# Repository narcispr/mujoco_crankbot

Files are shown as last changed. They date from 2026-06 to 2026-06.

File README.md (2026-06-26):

# Crank Bot

Crank Bot is a basic four-legged robot project. The name comes from its black look, but mechanically it is a small quadruped that can be 3D printed and assembled.

The repository includes the STL files in [`assets/`](assets/) and a first basic MuJoCo simulation model.

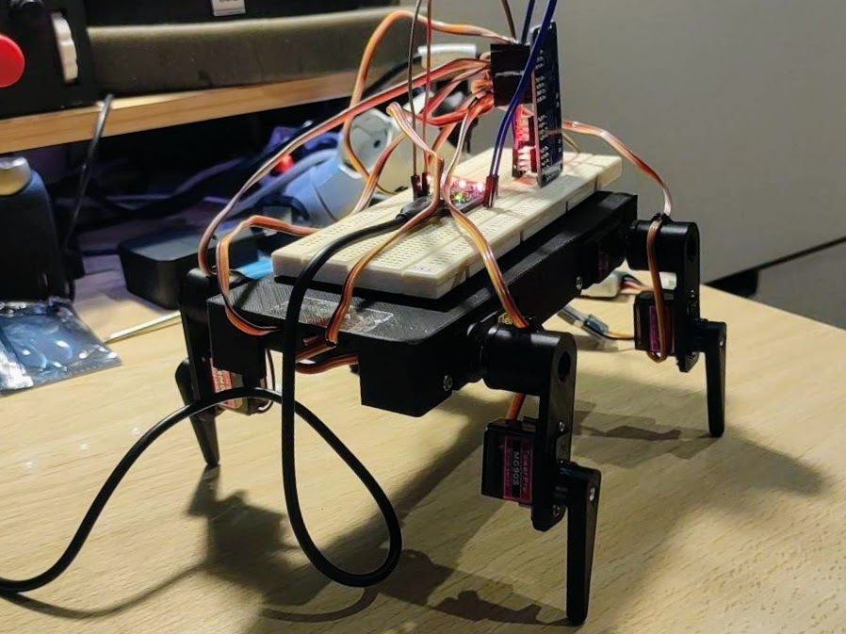
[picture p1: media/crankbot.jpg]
Crank Bot


## Bill of Materials

Initial BOM:

- 4x MG995 or MG996 servos
- 4x MG90S servos
- 1x PCA9685 servo driver
- 1x ESP32-C3 microcontroller
- 1x 5 V or 6 V BEC, minimum 5 A, preferably 10 A
- 1x MP1584 buck converter for the microcontroller
- 1x 2S LiPo battery
- 3D printed parts from [`assets/`](assets/)

## Simulation

The repository currently contains a basic MuJoCo XML model of the robot. A Python script will be added later to interact with the simulation.

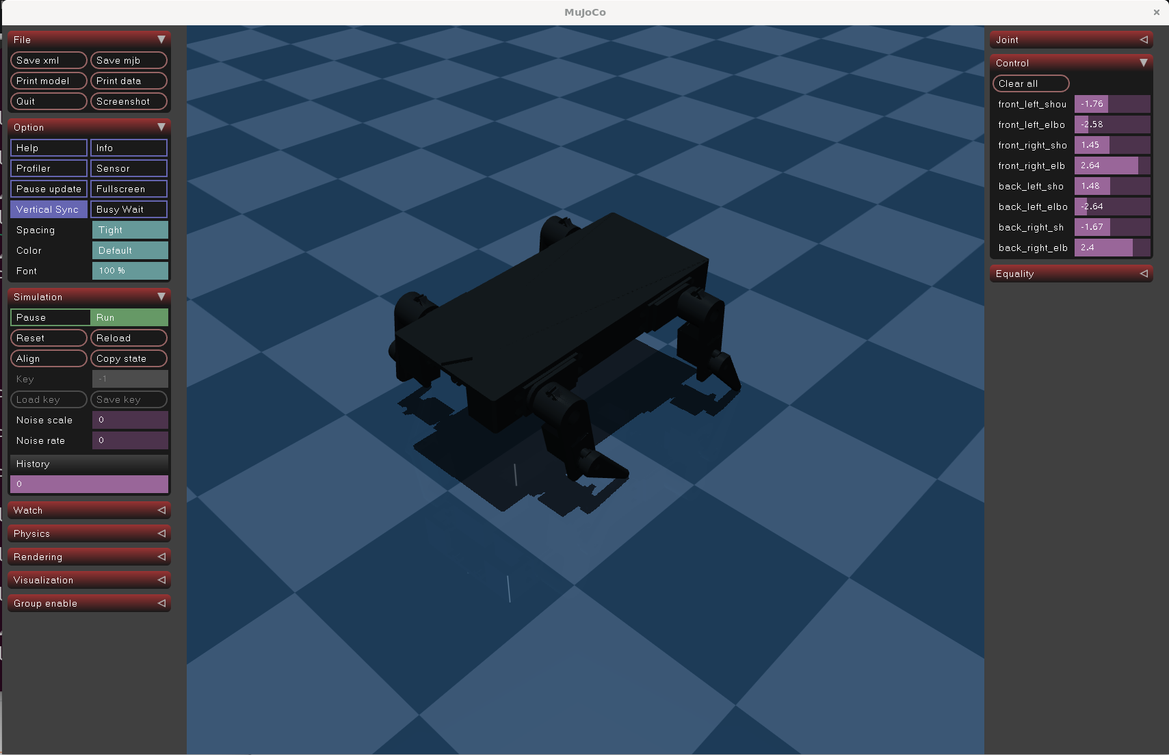
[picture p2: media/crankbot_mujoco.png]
Crank Bot in MuJoCo


## Control del robot real amb ESP32-C3

Aquesta versió substitueix el control Arduino bàsic de [`firmware/robo_dog_sketch.ino`](firmware/robo_dog_sketch.ino) per un bridge WiFi amb ESP32-C3:

- Firmware ESP32-C3: [`firmware/esp32_c3_servo_bridge/esp32_c3_servo_bridge.ino`](firmware/esp32_c3_servo_bridge/esp32_c3_servo_bridge.ino)
- Client PC: [`scripts/robot_client.py`](scripts/robot_client.py)
- Presets visibles: [`scripts/config/robot_presets.json`](scripts/config/robot_presets.json)

El PC envia 8 setpoints normalitzats en l'interval `[-1, 1]` per UDP. L'ESP els converteix a polsos PWM per al PCA9685 i limita la velocitat de canvi amb els paràmetres `minRpm` i `maxRpm` definits per cada servo. Això és un limitador de consigna: els MG995/MG996/MG90S no donen feedback de posició, per tant l'ESP no pot mesurar la RPM real.

Ordre dels 8 motors:

| Índex | Motor | Canal PCA9685 inicial |
| ---: | --- | ---: |
| 0 | `front_left_shoulder` | 8 |
| 1 | `front_left_elbow` | 9 |
| 2 | `front_right_shoulder` | 12 |
| 3 | `front_right_elbow` | 13 |
| 4 | `back_left_shoulder` | 10 |
| 5 | `back_left_elbow` | 11 |
| 6 | `back_right_shoulder` | 14 |
| 7 | `back_right_elbow` | 15 |

### Connexions

Connexions recomanades:

- PCA9685 `V+` a la font/BEC de servos de 5-6 V.
- PCA9685 `GND`, ESP32-C3 `GND` i GND de la font de servos units.
- PCA9685 `VCC` a `3V3` de l'ESP32-C3.
- PCA9685 `SDA` al GPIO `8` de l'ESP32-C3.
- PCA9685 `SCL` al GPIO `9` de l'ESP32-C3.
- Servos als canals `8..15` del PCA9685 segons la taula anterior.

No alimentis els servos des de l'USB ni des del pin `5V` de l'ESP. Els servos han de tenir una alimentació separada amb prou corrent, i només han de compartir GND amb l'ESP.

Si la teva placa ESP32-C3 no exposa I2C als GPIO `8/9`, canvia aquests valors al firmware:

```cpp
const int I2C_SDA_PIN = 8;
const int I2C_SCL_PIN = 9;
```

### Instal·lació de l'Arduino IDE

1. Instal·la Arduino IDE 2.x.
2. A `File > Preferences`, afegeix aquest URL a `Additional boards manager URLs`:

   ```text
   https://espressif.github.io/arduino-esp32/package_esp32_index.json
   ```

3. A `Tools > Board > Boards Manager`, instal·la `esp32` by Espressif Systems.
4. A `Library Manager`, instal·la:
   - `Adafruit PWM Servo Driver Library`
   - `Adafruit BusIO`
5. Obre [`firmware/esp32_c3_servo_bridge/esp32_c3_servo_bridge.ino`](firmware/esp32_c3_servo_bridge/esp32_c3_servo_bridge.ino).
6. A `Tools > Board`, tria la teva placa ESP32-C3. Si no surt exactament, prova `ESP32C3 Dev Module`.
7. Connecta l'ESP per USB i tria el port a `Tools > Port`.
8. Prem `Upload`.

Si la placa no entra en mode programació, mantén premut `BOOT`, prem i deixa anar `RESET`, i torna a pujar el firmware.

### Configuració WiFi de l'ESP

Per defecte, l'ESP crea una xarxa pròpia:

- SSID: `crankbot-esp32`
- Password: `crankbot123`
- IP de l'ESP: `192.168.4.1`
- Port UDP: `4210`

Connecta el PC a aquesta WiFi abans d'executar el client Python.

Si prefereixes que l'ESP entri a la teva WiFi, omple aquests camps al firmware:

```cpp
const char *WIFI_SSID = "nom_de_la_wifi";
const char *WIFI_PASSWORD = "password";
```

En aquest mode, obre el Serial Monitor a `115200` baud per veure la IP assignada i passa-la al client amb `--host`.

### Calibratge dels servos

Al firmware, cada servo té:

```cpp
{"front_left_shoulder", 8, 500, 1500, 2750, 2.0, 50.0, false}
```

Els camps són:

| Camp | Significat |
| --- | --- |
| Nom | Nom del joint |
| Canal | Canal del PCA9685 |
| `minUs` | Pols per a setpoint `-1` |
| `centerUs` | Pols per a setpoint `0` |
| `maxUs` | Pols per a setpoint `1` |
| `minRpm` | Pas mínim quan hi ha moviment |
| `maxRpm` | Velocitat màxima de canvi de consigna |
| `invert` | Inverteix el signe del setpoint |

Els valors inicials surten del sketch Arduino antic: `500 us`, `2500 us`, `2750 us` i centre `1500 us`. Abans d'executar la policy, prova motor a motor amb valors petits, per exemple `-0.2`, `0.0`, `0.2`, i ajusta `minUs`, `centerUs`, `maxUs` i `invert`.

### Client Python

Des del PC principal, crea l'entorn Python i instal·la dependències:

```bash
python -m venv .venv
source .venv/bin/activate
pip install -r requirements.txt
```

Per veure els presets disponibles:

```bash
python scripts/robot_client.py list-presets
```

Per enviar una posició predefinida:

```bash
python scripts/robot_client.py preset center
python scripts/robot_client.py preset stand_approx --duration 3
python scripts/robot_client.py preset folded_approx --duration 3
```

Per defecte, aquests comandaments també obren MuJoCo i mostren el mateix moviment al simulador. Si només vols enviar a l'ESP sense simulador:

```bash
python scripts/robot_client.py --disable-mujoco preset stand_approx --duration 3
```

Per enviar 8 valors manuals:

```bash
python scripts/robot_client.py manual 0 0 0 0 0 0 0 0
python scripts/robot_client.py manual 0.2 0 -0.2 0 0.2 0 -0.2 0 --duration 2
```

En mode manual amb MuJoCo actiu, els 8 valors manuals són el target del simulador. El client llegeix contínuament les posicions reals dels joints simulats (`qpos`) i envia aquestes posicions a l'ESP. Per saltar aquest comportament i enviar directament els 8 valors manuals:

```bash
python scripts/robot_client.py --disable-mujoco manual 0.2 0 -0.2 0 0.2 0 -0.2 0 --duration 2
```

Per comprovar comunicació amb l'ESP:

```bash
python scripts/robot_client.py command PING
python scripts/robot_client.py command STATUS
python scripts/robot_client.py command STOP
```

Si l'ESP està connectat a una WiFi externa, usa la IP que surt pel Serial Monitor:

```bash
python scripts/robot_client.py --host 192.168.1.123 command STATUS
```

### Executar una policy al robot

El client pot carregar una policy SAC de Stable-Baselines3 i enviar les accions al robot:

```bash
python scripts/robot_client.py policy --model logs/crankbot_walk_gym/run_xxx/final_model.zip
```

Si no passes `--model`, busca l'últim model sota `logs/crankbot_walk_gym`.

El programa demana:

- `Goal range in meters`: distància inicial al goal.
- `Goal bearing in degrees`: angle relatiu del goal respecte al robot.
- `Maximum execution time in seconds`: temps màxim d'execució.

També pots passar-ho sense prompts:

```bash
python scripts/robot_client.py policy \
  --model logs/crankbot_walk_gym/run_xxx/final_model.zip \
  --goal-range 0.5 \
  --goal-bearing-deg 0 \
  --max-time 8
```

Abans d'executar la policy, el client envia `q_stand` durant `--prime-duration`, perquè les policies s'han entrenat sortint d'una postura propera a `q_stand`.

Amb MuJoCo actiu, que és el comportament per defecte, el range i bearing inicials creen un goal visible al `goal_site` del simulador. A partir d'aquí, cada crida a la policy usa el range i bearing actuals entre el robot simulat i aquest goal. El feedback del goal ve del simulador, no del robot real.

Si vols executar la policy sense obrir ni avançar MuJoCo:

```bash
python scripts/robot_client.py --disable-mujoco policy \
  --model logs/crankbot_walk_gym/run_xxx/final_model.zip \
  --goal-range 0.5 \
  --goal-bearing-deg 0 \
  --max-time 8
```

Per al robot real, entrena o carrega una policy amb observacions d'actor, és a dir amb `--disable-privileged`. Una policy entrenada amb l'observació privilegiada de 80 valors espera estat de simulador que el robot real no té.

Important: el control dels servos reals continua sent open-loop. El client sap les consignes que ha enviat, l'historial d'accions, la fase de la marxa i, si MuJoCo està actiu, el goal respecte al robot simulat. No sap si el robot real ha avançat o ha girat. Si afegeixes odometria, càmera o localització externa, s'ha d'actualitzar `goal_range` i `goal_bearing` dins de [`scripts/robot_client.py`](scripts/robot_client.py).

## Training

The Gymnasium environment is [`scripts/crankbot_walk_gym_env.py`](scripts/crankbot_walk_gym_env.py). It wraps the CPU MuJoCo vectorized environment as a single-env Gym API for SAC training.

| Mode | Observation size | Contents |
| --- | ---: | --- |
| Default | 80 | Actor observation + privileged simulator state |
| `--disable-privileged` | 68 | Actor observation only |

Actor observation:

| Term | Size | Meaning |
| --- | ---: | --- |
| `q_cmd_history` | 32 | 4-step history of 8 commanded joint targets, as `q_cmd - q_stand` |
| `action_history` | 32 | 4-step history of 8 normalized actions |
| `goal_bearing / pi` | 1 | Relative goal direction |
| `goal_range / target_goal_range` | 1 | Normalized distance to the goal |
| `sin(phase), cos(phase)` | 2 | Gait phase signal |

Standing reference pose:

| Joint order | `front_left_shoulder` | `front_left_elbow` | `front_right_shoulder` | `front_right_elbow` | `back_left_shoulder` | `back_left_elbow` | `back_right_shoulder` | `back_right_elbow` |
| --- | ---: | ---: | ---: | ---: | ---: | ---: | ---: | ---: |
| `q_stand` rad | -1.15 | -2.34 | 1.15 | 2.34 | 2.00 | -2.34 | -2.00 | 2.34 |

Privileged extra observation:

| Term | Size | Meaning |
| --- | ---: | --- |
| `base_velocity_body` | 3 | Local base velocity, including yaw rate |
| `base_z` | 1 | Base height |
| `roll_pitch` | 2 | Base tilt |
| `foot_contacts` | 4 | Foot contact flags |
| `leg_contact` | 1 | Upper-leg ground contact |
| `body_contact` | 1 | Base ground contact |

Actions are 8 normalized joint command increments:

$$
q_{cmd,t+1} = clip(q_{cmd,t} + a_t \cdot action\_scale,\ q_{min},\ q_{max}),\quad a_t \in [-1, 1]^8
$$

Reward:

$$
r = -tanh(goal\_range / goal\_reward\_scale) - c_s ||a_t-a_{t-1}||^2 - c_a ||a_t||^2 - p_{idle} - p_{leg} - p_{lower} - p_{body} - p_{fall}
$$

| Term | Meaning |
| --- | --- |
| $-tanh(goal\_range / goal\_reward\_scale)$ | Goal progress term; less negative as the robot gets closer to the target |
| $-c_s \|\|a_t-a_{t-1}\|\|^2$ | Smoothness penalty for abrupt action changes |
| $-c_a \|\|a_t\|\|^2$ | Action magnitude penalty |
| $-p_{idle}$ | Penalty for sending nearly zero action while the goal is not reached |
| $-p_{leg}$ | Penalty when upper-leg collision geoms touch the floor |
| $-p_{lower}$ | Penalty when lower-leg collision geoms touch the floor |
| $-p_{body}$ | Penalty when the base touches the floor |
| $-p_{fall}$ | Fall penalty when base height is below the fall threshold |

### Training MJX/Warp amb Playground

Per entrenar a GPU amb l'entorn MJX actor-only i provar el backend Warp/Playground, crea un venv nou amb Python 3.11 o superior. Un `uv pip install` sobre el `.venv` antic no canvia la versió de Python.

```bash
uv venv --python 3.11
source .venv/bin/activate
uv pip install -r requirements.txt
```

Entrenament PPO amb 2048 entorns:

```bash
python scripts/train.mjx.py \
  --algorithm ppo \
  --backend warp \
  --num-envs 2048 \
  --num-eval-envs 256 \
  --timesteps 10000000
```

Entrenament SAC:

```bash
python scripts/train.mjx.py \
  --algorithm sac \
  --backend warp \
  --num-envs 2048 \
  --num-eval-envs 256 \
  --timesteps 10000000
```

Notes ràpides:

- Si surt `backend='warp'` no disponible, comprova que el venv sigui Python 3.11+ i que `warp-lang` i `playground[learning]` s'hagin instal·lat.
- Si veus errors de CUDA/JAX, revisa que la versió instal·lada de `jax[cuda13]` encaixi amb el driver de la GPU.
- Si vols comprovar el pipeline abans d'un run llarg, baixa `--num-envs 32 --num-eval-envs 8 --timesteps 1000 --logger none --no-checkpoints`.
- Si Warp continua donant problemes, prova temporalment `--backend mjx` per separar errors de l'entorn dels errors del backend.

After training with SAC, this behavior has been obtained:

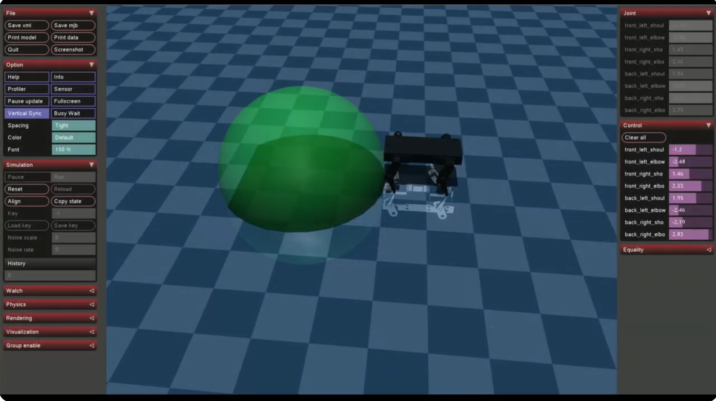
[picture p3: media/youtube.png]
Watch the video (https://youtu.be/LTj4IBt9pyA)


## Future Work

- Include some dynamics/noise randomization in the learning.
- Execute the trained policy in the real hardware.

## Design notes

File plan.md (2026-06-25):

# mplementation plan for rsl_rl + PPO + privileged_obs

## 1. Goal

Implement a MuJoCo CPU vectorized environment for the 8-servo quadruped robot using:

- rsl_rl
- PPO
- asymmetric actor-critic
- actor observations based only on information available on the real robot
- privileged critic observations using simulator-only state

The robot already exists as a MuJoCo XML model at file crank_bot.xml with:

- free root body
- 8 position-controlled joints
- visualization meshed geoms
- 2 x contact geoms per leg + 1 for the body

The environment will train a policy to track commanded forward velocity and yaw velocity.

## 2. Simulation timing

Use MuJoCo at:

simulation_dt = 0.002 s
simulation_frequency = 500 Hz

Use policy/control at:

dt_control = 0.1 s
control_frequency = 10 Hz
decimation = 50

That means:

1 policy step = 50 MuJoCo mj_step calls

Episode length:

max_episode_steps = 80
episode_time = 8.0 s

Success is defined if during the last 20 steps the average speed matches (with some error) the desired speed.

Do not terminate on success. Use success only as a curriculum signal.

## 3. Action definition

The action is continuous:

action ∈ [-1, 1]^8

Each action component represents an increment in commanded joint target.

Use different scales for shoulders and elbows:

shoulder_action_scale = 0.07 rad/step
elbow_action_scale    = 0.10 rad/step

Assume a fixed joint ordering, for example:

0 front_left_shoulder
1 front_left_elbow
2 front_right_shoulder
3 front_right_elbow
4 back_left_shoulder
5 back_left_elbow
6 back_right_shoulder
7 back_right_elbow

Define:

action_scale = [
    0.07, 0.10,
    0.07, 0.10,
    0.07, 0.10,
    0.07, 0.10,
]

Update commanded positions:

q_cmd_next = q_cmd_current + action_scale * action

Articulation limits and standing pose (q_stand) are defined as:

- front_left_shoulder => limits: [-pi, 0], standing -1.15
- front_left_elbow => limits: [-pi, 0], standing -2.34
- front_right_shoulder => limits: [0, pi], standing 1.15
- front_right_elbow => limits: [0, pi], standing 2.34
- back_left_shoulder => limits: [0, pi], standing 2
- back_left_elbow => limits: [-pi, 0], standing -2.34
- back_right_shoulder => limits: [-pi, 0], standing -2
- back_right_elbow => limits: [0, pi], standing 2.34

Clip around the standing pose:

q_cmd_next = clip(q_cmd_next, q_stand - q_limit, q_stand + q_limit)

Start with conservative limits:

The MuJoCo position actuators receive:

data.ctrl[:] = q_cmd_next

assuming each actuator ctrlrange is in radians and matches the joint target range.

## 4. Desired commands

At each episode reset, sample one command and keep it constant for the full episode.

Actor receives normalized commands:

- command_vx = vx_des / GLOBAL_MAX_VX
- command_wz = wz_des / GLOBAL_MAX_WZ

where

- vx_des = uniform(-current_max_vx, current_max_vx)
- wz_des = uniform(-current_max_wz, current_max_wz)

Start with small velocities:

current_max_vx = 0.05 m/s
current_max_wz = 0.20 rad/s

Later curriculum may increase them to:

current_max_vx = 0.10 m/s
current_max_wz = 0.35 rad/s

Then:

current_max_vx = 0.15 m/s
current_max_wz = 0.50 rad/s

Define 

GLOBAL_MAX_VX  = 0.15 m/s
GLOBAL_MAX_WZ = 0.50 rad/s

## 5. Gait phase

Maintain a phase variable per environment:

phase += 2.0 * pi * gait_frequency * dt_control
phase = phase % (2.0 * pi)

Initial value at reset:

phase = uniform(0, 2*pi)

Start with:

gait_frequency = 1.0 Hz

Observation uses:

sin_phase = sin(phase)
cos_phase = cos(phase)

## 6. Actor observation

The actor should not receive MuJoCo qpos or qvel directly, because the real MG996/MG90 servos do not provide real feedback.

Use commanded joint history instead:

q_cmd_history, not q_real

Use relative commanded positions:

q_cmd_rel = q_cmd - q_stand

Use history length:

N = 4

Actor observation:

actor_obs =
[
  q_cmd_rel[t],
  q_cmd_rel[t-1],
  q_cmd_rel[t-2],
  q_cmd_rel[t-3],

  action[t-1],
  action[t-2],
  action[t-3],
  action[t-4],

  command_vx, 
  command_wz,

  sin(phase),
  cos(phase)
]

Dimension:

4 * 8 + 4 * 8 + 2 + 2 = 68

Rationale:

q_cmd_history:
  approximates what the real robot knows: what positions were commanded.

action_history:
  gives the policy recent control intent, especially useful when clipping,
  saturation, delays, and different shoulder/elbow scales are present.

command_vx_norm and command_wz_norm:
  tell the policy what the user wants.

phase:
  provides an internal periodic clock that helps discover rhythmic gaits.

## 7. Critic observation

Use privileged information for the critic.

Critic observation:

critic_obs =
[
  actor_obs,

  measured_vx_body,
  measured_vy_body,
  measured_wz_body,

  base_z,
  roll,
  pitch,

  foot_contact_FL,
  foot_contact_FR,
  foot_contact_BL,
  foot_contact_BR,

  body_contact
]

Dimension:

68 + 3 + 3 + 4 + 1 = 79

Where:

measured_vx_body:
  robot forward velocity expressed in body frame

measured_vy_body:
  lateral velocity in body frame

measured_wz_body:
  yaw rate in body frame or world z yaw rate

base_z:
  root/base height

roll, pitch:
  body orientation, excluding yaw

foot contacts:
  booleans or floats from MuJoCo contact detection

body_contact:
  1 if torso/base touches the floor, else 0

Use the body named "base" for the spoeed height and orientation and the spheres named "[front/back]_[left/right]_lower_leg_foot" for the feet contacts.

Rationale:

The critic is allowed to see simulator-only information.
This improves value estimation during PPO training.
The actor will not receive these quantities at deployment time.

## 8. Reward

Use:

evx = (vx_des - vx_measured) / GLOBAL_MAX_VX
ewz = (wz_des - wz_measured) / GLOBAL_MAX_WZ

r_vx = exp(-k_vx * evx**2)
r_wz = exp(-k_wz * ewz**2)

reward = (
    1.0 * r_vx
    + 0.5 * r_wz
    - 0.005 * np.sum((action - last_action)**2)
    - 0.001 * np.sum(action**2)
    - 1.0 * body_contact
    - 2.0 * fall
)

Initial constants:

k_vx = 4.0
k_wz = 2.0

## 9. Body contact penalty

Body contact:

body_contact = base collision geom touches floor

use body_contact as a penalty but not termination.

## 10. Success metric for curriculum

Do not terminate on success initially.

Define success at episode end:

success = (
  not body_contact
  and mean_abs_vx_error_last_20_steps < vx_threshold
  and mean_abs_wz_error_last_20_steps < wz_threshold
)

Initial thresholds:

vx_threshold = 0.025 m/s
wz_threshold = 0.05 rad/s

Later tighten:

vx_threshold = 0.02 m/s
wz_threshold = 0.04 rad/s

Then:

vx_threshold = 0.015 m/s
wz_threshold = 0.035 rad/s

Track:

success_rate = successes_last_100_episodes / 100. Ensure that 100 episodes have already completed.

Use success metric to update all curriculum variables (see 11)

## 11. Adaptive curriculum

Maintain curriculum variables:

current_max_vx
current_max_wz
initial_pose_noise
regularization_scale
success_thresholds

Initial values:

current_max_vx = 0.05
current_max_wz = 0.00
initial_pose_noise = 0.10 rad
smoothness_coef = 0.002
action_coef = 0.0005
body_contact_penalty = 0.5

Target final values:

max_vx = 0.15
max_wz = 0.50
initial_pose_noise = 0.50 rad
smoothness_coef = 0.005
action_coef = 0.001
body_contact_penalty = 1.0

Every time:

success_rate_last_100 > 0.75

increase difficulty slightly:

max_vx *= 1.15
max_wz += 0.05
initial_pose_noise += 0.03
smoothness_coef += small_increment
tighten success thresholds slightly

Clamp to maximum values.

I would not start with backward walking. Start forward only.

## 12. Reset logic

At reset:

q_cmd = q_stand + uniform(-initial_pose_noise, +initial_pose_noise)
q_cmd = clip(q_cmd, q_stand - q_limit, q_stand + q_limit)

Set MuJoCo joint positions close to q_cmd, but optionally add small physical mismatch:

q_real = q_cmd + uniform(-servo_position_error, servo_position_error)

Start with:

servo_position_error = 0.0

Later:

servo_position_error = 0.03 rad

Set velocities to small random values:

qvel = uniform(-0.05, 0.05)

Set root pose:

base at nominal height
small roll/pitch noise
yaw random optional

Initialize histories:

q_cmd_history[:] = q_cmd - q_stand
action_history[:] = 0
phase = uniform(0, 2*pi)

## 13. Environment API for rsl_rl

Implement a vectorized environment class with buffers:

self.obs_buf              # actor obs, shape [num_envs, 68]
self.privileged_obs_buf   # critic obs, shape [num_envs, 79]
self.rew_buf              # shape [num_envs]
self.reset_buf            # shape [num_envs]
self.episode_length_buf   # shape [num_envs]

Required methods conceptually:

reset()
step(actions)
get_observations()
get_privileged_observations()

Depending on exact rsl_rl version, match the expected VecEnv interface.

The step(actions) function:

1. clip actions to [-1, 1]
2. update q_cmd with shoulder/elbow scales
3. clip q_cmd around q_stand
4. write q_cmd to MuJoCo actuator controls
5. run decimation MuJoCo steps
6. compute contacts
7. compute base velocities/orientation
8. compute reward
9. compute done/reset
10. update histories
11. fill obs_buf and privileged_obs_buf
12. reset environments that are done
15. Training configuration

Start with:

num_envs = 32
control_frequency = 10 Hz
episode_steps = 80

PPO rough starting values:

num_steps_per_env = 80
num_learning_epochs = 5
num_mini_batches = 4
gamma = 0.99
lam = 0.95
learning_rate = 3e-4
entropy_coef = 0.01
clip_param = 0.2
desired_kl = 0.01

Actor-critic network:

actor hidden dims:  [256, 256, 128]
critic hidden dims: [256, 256, 128]
activation: ELU or Tanh

Observation normalization is strongly recommended.

## Notes

Be sure that the training autoreset resets not only physics state and obs, but also arbitrary custom state. Since this environment’s observation is mostly command/history state, add something to resets/resample those fields instead of silently carrying stale histories across episodes.

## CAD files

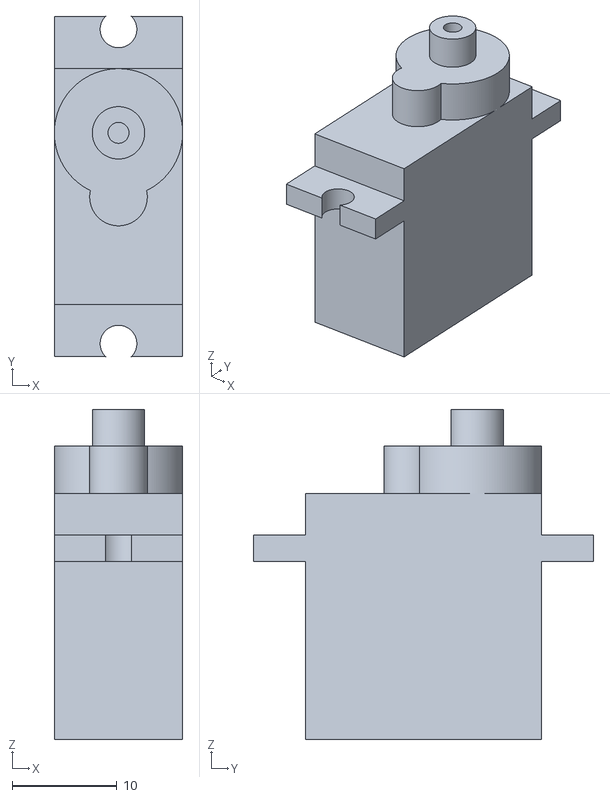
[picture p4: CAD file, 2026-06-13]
assets/mg90.stl
12.2 x 32.5 x 31.5

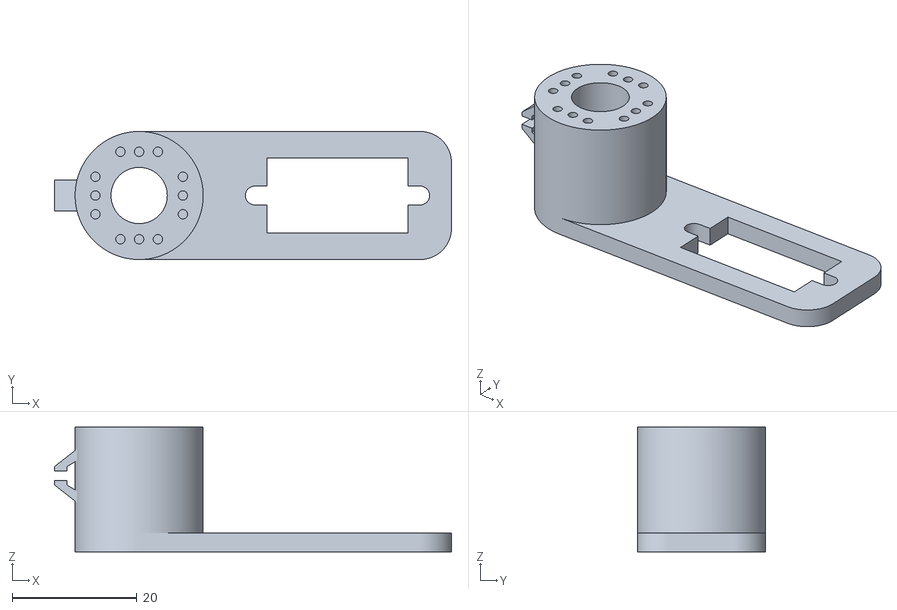
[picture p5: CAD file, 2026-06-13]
assets/leg1.stl
63.6 x 20.5 x 20.0

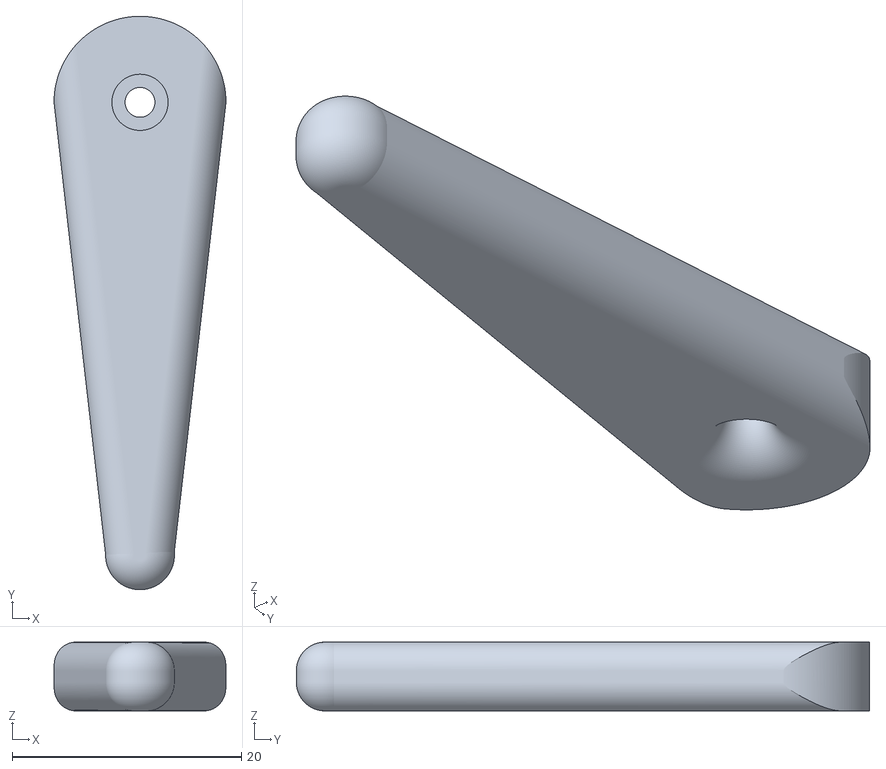
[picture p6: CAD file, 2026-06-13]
assets/leg2.stl
15.0 x 50.0 x 6.00

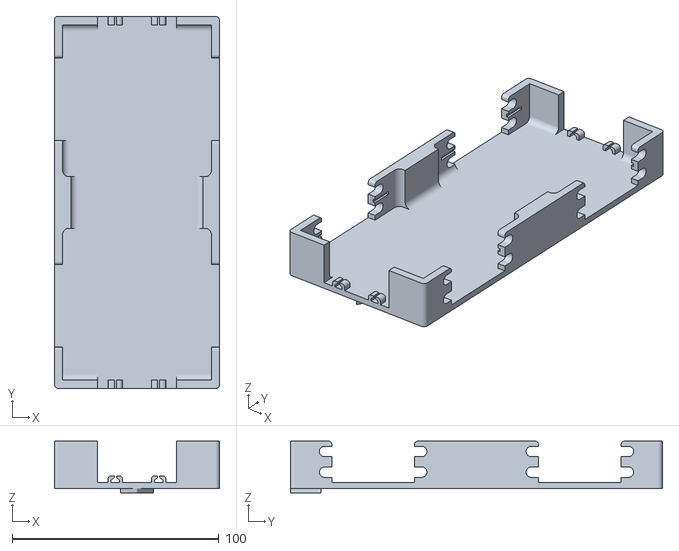
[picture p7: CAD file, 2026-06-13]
assets/base2b.stl
80.0 x 180.0 x 25.0

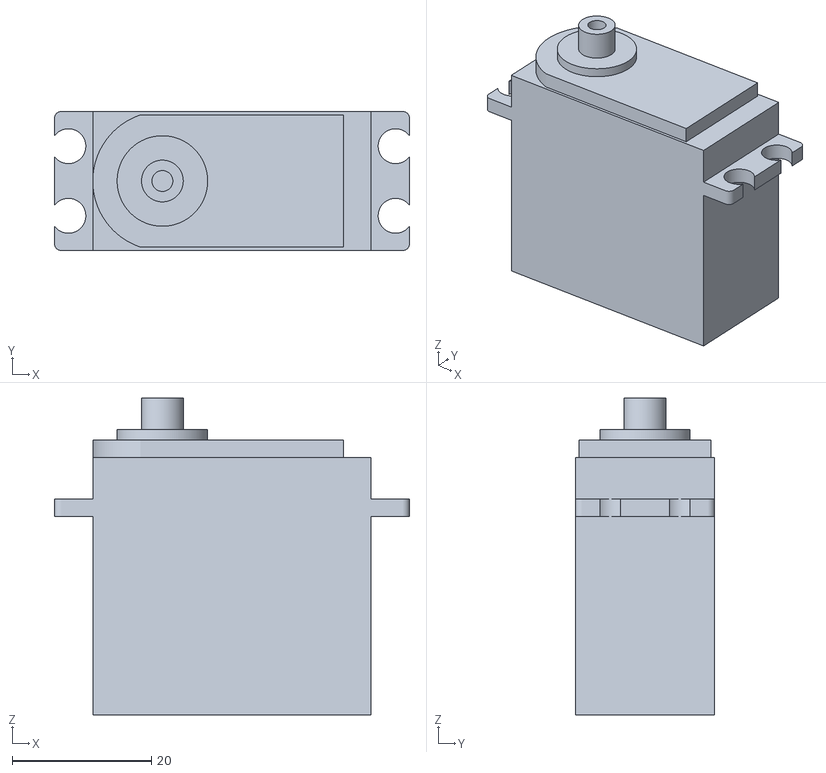
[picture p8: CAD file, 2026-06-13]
assets/MG995.stl
51.0 x 20.0 x 45.5

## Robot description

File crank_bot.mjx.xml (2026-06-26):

<?xml version="1.0" encoding="utf-8"?>
<mujoco model="crank_bot">
  <compiler angle="radian" meshdir="assets" inertiafromgeom="true" autolimits="true"/>
  <option timestep="0.002" gravity="0 0 -9.81"/>
  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
  <worldbody>
    <body name="root" pos="0 0 0.1" euler="0 3.14159 0">
        <freejoint name="root_freejoint"/>
        <body name="base" pos="0.0 0.0 0.0">
            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
            <body name="servo1" pos="0.015 -0.05 0.013" euler="0 -1.5708 1.5708">
                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
                <body name="front_left_leg" pos="-0.01 -0.0 0.0825" euler="0 3.14159 0">
                    <joint name="front_left_shoulder_joint" type="hinge" pos="0 0 0" axis="0 0 1" limited="true" range="-180 0" damping="0.15" frictionloss="0.05" armature="0.0005"/>
                    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
                    <body name="front_left_knee" pos="0.03 0.0 0.022" euler="0 3.14159 1.5708">    
                        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
                        <body name="front_left_lower_leg" pos="0.00 0.005 0.027" euler="0 0 0">
                            <joint name="front_left_elbow_joint" type="hinge" pos="0.0 0.0 0.0" axis="0 0 1" limited="true" range="-180 0" damping="0.08" frictionloss="0.02" armature="0.0002"/>
                            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
                        </body>
                    </body>
                </body>
            </body>
            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
            <body name="servo2" pos="-0.015 -0.05 0.013" euler="0 1.5708 1.5708">
                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
                <body name="front_right_leg" pos="-0.01 -0.0 0.0825" euler="0 3.14159 0">
                    <joint name="front_right_shoulder_joint" type="hinge" pos="0 0 0" axis="0 0 1" limited="true" range="0 180" damping="0.15" frictionloss="0.05" armature="0.0005"/>
                    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
                    
                    <body name="front_right_knee" pos="0.03 0.0 0.022" euler="0 3.14159 1.5708">    
                        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
                        
                        <body name="front_right_lower_leg" pos="0.00 0.005 0.027" euler="0 0 0">
                            <joint name="front_right_elbow_joint" type="hinge" pos="0.0 0.0 0.0" axis="0 0 1" limited="true" range="0 180" damping="0.08" frictionloss="0.02" armature="0.0002"/>
                            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
                        </body>
                    </body>
                </body>
            </body>
            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
             <body name="servo3" pos="0.015 0.05 0.013" euler="0 -1.5708 -1.5708">
                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
                <body name="back_left_leg" pos="-0.01 -0.0 0.0825" euler="0 3.14159 0">
                    <joint name="back_left_shoulder_joint" type="hinge" pos="0 0 0" axis="0 0 1" limited="true" range="0 180" damping="0.15" frictionloss="0.05" armature="0.0005"/>
                    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
                    
                    <body name="back_left_knee" pos="0.03 0.0 0.022" euler="0 3.14159 1.5708">    
                        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
                        <body name="back_left_lower_leg" pos="0.00 0.005 0.027" euler="0 0 0">
                            <joint name="back_left_elbow_joint" type="hinge" pos="0.0 0.0 0.0" axis="0 0 1" limited="true" range="-180 0" damping="0.08" frictionloss="0.02" armature="0.0002"/>
                            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
                        </body>
                    </body>
                </body>
            </body>
            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
            <body name="servo4" pos="-0.015 0.05 0.013" euler="0 1.5708 -1.5708">
                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
                <body name="back_right_leg" pos="-0.01 -0.0 0.0825" euler="0 3.14159 0">
                    <joint name="back_right_shoulder_joint" type="hinge" pos="0 0 0" axis="0 0 1" limited="true" range="-180 0" damping="0.15" frictionloss="0.05" armature="0.0005"/>
                    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
                    
                    <body name="back_right_knee" pos="0.03 0.0 0.022" euler="0 3.14159 1.5708">    
                        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
                        <body name="back_right_lower_leg" pos="0.00 0.005 0.027" euler="0 0 0">
                            <joint name="back_right_elbow_joint" type="hinge" pos="0.0 0.0 0.0" axis="0 0 1" limited="true" range="0 180" damping="0.08" frictionloss="0.02" armature="0.0002"/>
                            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
                        </body>
                    </body>
                </body>
            </body>
        </body>
    </body>
</worldbody>

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

<actuator>
    <position name="front_left_shoulder_pos" joint="front_left_shoulder_joint" kp="8" kv="0.4" ctrlrange="-3.14159 0.0" forcerange="-1.2 1.2"/>
    <position name="front_left_elbow_pos" joint="front_left_elbow_joint" kp="3" kv="0.15" ctrlrange="-3.14159 0.0" forcerange="-0.25 0.25"/>
    <position name="front_right_shoulder_pos" joint="front_right_shoulder_joint" kp="8" kv="0.4" ctrlrange="0.0 3.14159" forcerange="-1.2 1.2"/>
    <position name="front_right_elbow_pos" joint="front_right_elbow_joint" kp="3" kv="0.15" ctrlrange="0.0 3.14159" forcerange="-0.25 0.25"/>
    <position name="back_left_shoulder_pos" joint="back_left_shoulder_joint" kp="8" kv="0.4" ctrlrange="0.0 3.14159" forcerange="-1.2 1.2"/>
    <position name="back_left_elbow_pos" joint="back_left_elbow_joint" kp="3" kv="0.15" ctrlrange="-3.14159 0.0" forcerange="-0.25 0.25"/>
    <position name="back_right_shoulder_pos" joint="back_right_shoulder_joint" kp="8" kv="0.4" ctrlrange="-3.14159 0.0" forcerange="-1.2 1.2"/>
    <position name="back_right_elbow_pos" joint="back_right_elbow_joint" kp="3" kv="0.15" ctrlrange="0.0 3.14159" forcerange="-0.25 0.25"/>
</actuator>

</mujoco>

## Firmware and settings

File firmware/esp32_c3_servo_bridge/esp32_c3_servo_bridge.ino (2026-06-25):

#include <Adafruit_PWMServoDriver.h>
#include <WiFi.h>
#include <WiFiUdp.h>
#include <Wire.h>
#include <math.h>
#include <string.h>

// Network mode:
// - Leave WIFI_SSID empty to make the ESP32-C3 create its own access point.
// - Fill WIFI_SSID/WIFI_PASSWORD to join your home/lab WiFi instead.
const char *WIFI_SSID = "";
const char *WIFI_PASSWORD = "";
const char *AP_SSID = "crankbot-esp32";
const char *AP_PASSWORD = "crankbot123";

const uint16_t UDP_PORT = 4210;
const uint32_t COMMAND_TIMEOUT_MS = 750;
const uint32_t SERVO_UPDATE_PERIOD_MS = 20;  // 50 Hz, matching hobby servos.

// Change these pins if your ESP32-C3 board exposes I2C elsewhere.
const int I2C_SDA_PIN = 8;
const int I2C_SCL_PIN = 9;
const uint8_t PCA9685_ADDRESS = 0x40;

Adafruit_PWMServoDriver pca = Adafruit_PWMServoDriver(PCA9685_ADDRESS);
WiFiUDP udp;

struct ServoConfig {
  const char *name;
  uint8_t channel;
  uint16_t minUs;
  uint16_t centerUs;
  uint16_t maxUs;
  float minRpm;
  float maxRpm;
  bool invert;
};

// Joint order expected by the Python client:
// 0 front_left_shoulder
// 1 front_left_elbow
// 2 front_right_shoulder
// 3 front_right_elbow
// 4 back_left_shoulder
// 5 back_left_elbow
// 6 back_right_shoulder
// 7 back_right_elbow
//
// Initial pulse limits come from firmware/robo_dog_sketch.ino.
// Tune centerUs per joint after mounting the servos. Setpoint 0.0 should be
// the mechanically safe neutral/standing reference used by the PC client.
ServoConfig servos[8] = {
    {"front_left_shoulder", 8, 500, 1500, 2750, 2.0, 50.0, false},
    {"front_left_elbow", 9, 500, 1500, 2750, 2.0, 80.0, false},
    {"front_right_shoulder", 12, 500, 1500, 2500, 2.0, 50.0, false},
    {"front_right_elbow", 13, 500, 1500, 2750, 2.0, 80.0, false},
    {"back_left_shoulder", 10, 500, 1500, 2500, 2.0, 50.0, false},
    {"back_left_elbow", 11, 500, 1500, 2750, 2.0, 80.0, false},
    {"back_right_shoulder", 14, 500, 1500, 2500, 2.0, 50.0, false},
    {"back_right_elbow", 15, 500, 1500, 2750, 2.0, 80.0, false},
};

float currentUs[8];
float targetUs[8];
float lastSetpoint[8];
uint32_t lastCommandMs = 0;
uint32_t lastServoUpdateMs = 0;

float clampFloat(float value, float low, float high) {
  if (value < low) {
    return low;
  }
  if (value > high) {
    return high;
  }
  return value;
}

float setpointToPulseUs(const ServoConfig &servo, float setpoint) {
  float value = clampFloat(setpoint, -1.0, 1.0);
  if (servo.invert) {
    value = -value;
  }

  if (value >= 0.0) {
    return servo.centerUs + value * (servo.maxUs - servo.centerUs);
  }
  return servo.centerUs + value * (servo.centerUs - servo.minUs);
}

void setTargetsFromSetpoints(float setpoints[8]) {
  for (int i = 0; i < 8; ++i) {
    lastSetpoint[i] = clampFloat(setpoints[i], -1.0, 1.0);
    targetUs[i] = setpointToPulseUs(servos[i], lastSetpoint[i]);
  }
  lastCommandMs = millis();
}

void holdCurrentPosition() {
  for (int i = 0; i < 8; ++i) {
    targetUs[i] = currentUs[i];
  }
}

void writeAllServosNow() {
  for (int i = 0; i < 8; ++i) {
    pca.writeMicroseconds(servos[i].channel, (uint16_t)(currentUs[i] + 0.5));
  }
}

void updateServos() {
  const uint32_t now = millis();
  if (now - lastServoUpdateMs < SERVO_UPDATE_PERIOD_MS) {
    return;
  }

  const float dt = (now - lastServoUpdateMs) / 1000.0;
  lastServoUpdateMs = now;

  if (now - lastCommandMs > COMMAND_TIMEOUT_MS) {
    holdCurrentPosition();
  }

  for (int i = 0; i < 8; ++i) {
    const ServoConfig &servo = servos[i];
    const float delta = targetUs[i] - currentUs[i];
    const float absDelta = fabs(delta);
    if (absDelta < 0.5) {
      currentUs[i] = targetUs[i];
    } else {
      const float pulseRangeUs = servo.maxUs - servo.minUs;
      float maxStepUs = servo.maxRpm * dt * pulseRangeUs / 30.0;
      float minStepUs = servo.minRpm * dt * pulseRangeUs / 30.0;
      maxStepUs = max(maxStepUs, 1.0f);
      minStepUs = min(minStepUs, maxStepUs);

      float stepUs = min(absDelta, maxStepUs);
      if (absDelta > minStepUs) {
        stepUs = max(stepUs, minStepUs);
      }
      currentUs[i] += (delta > 0.0 ? stepUs : -stepUs);
    }
    pca.writeMicroseconds(servo.channel, (uint16_t)(currentUs[i] + 0.5));
  }
}

bool parseSetCommand(char *packet, float values[8]) {
  char *cursor = packet;
  while (*cursor == ' ' || *cursor == '\t') {
    ++cursor;
  }

  if (strncmp(cursor, "SET", 3) == 0) {
    cursor += 3;
  }

  for (int i = 0; i < 8; ++i) {
    while (*cursor == ' ' || *cursor == '\t' || *cursor == ',') {
      ++cursor;
    }
    if (*cursor == '\0' || *cursor == '\r' || *cursor == '\n') {
      return false;
    }

    char *endPtr = nullptr;
    values[i] = strtof(cursor, &endPtr);
    if (endPtr == cursor) {
      return false;
    }
    cursor = endPtr;
  }
  return true;
}

void sendStatus(IPAddress remoteIp, uint16_t remotePort, const char *prefix) {
  udp.beginPacket(remoteIp, remotePort);
  udp.print(prefix);
  udp.print(" ip=");
  udp.print(WiFi.getMode() == WIFI_AP ? WiFi.softAPIP() : WiFi.localIP());
  udp.print(" setpoints=");
  for (int i = 0; i < 8; ++i) {
    if (i > 0) {
      udp.print(",");
    }
    udp.print(lastSetpoint[i], 3);
  }
  udp.print(" pulses=");
  for (int i = 0; i < 8; ++i) {
    if (i > 0) {
      udp.print(",");
    }
    udp.print((int)(currentUs[i] + 0.5));
  }
  udp.endPacket();
}

void handleUdp() {
  char packet[256];
  const int packetSize = udp.parsePacket();
  if (packetSize <= 0) {
    return;
  }

  const int len = udp.read(packet, min(packetSize, (int)sizeof(packet) - 1));
  packet[len] = '\0';

  IPAddress remoteIp = udp.remoteIP();
  uint16_t remotePort = udp.remotePort();

  if (strncmp(packet, "PING", 4) == 0 || strncmp(packet, "STATUS", 6) == 0) {
    sendStatus(remoteIp, remotePort, "OK");
    return;
  }

  if (strncmp(packet, "STOP", 4) == 0) {
    holdCurrentPosition();
    lastCommandMs = millis();
    sendStatus(remoteIp, remotePort, "OK");
    return;
  }

  if (strncmp(packet, "CENTER", 6) == 0) {
    float zeros[8] = {0.0, 0.0, 0.0, 0.0, 0.0, 0.0, 0.0, 0.0};
    setTargetsFromSetpoints(zeros);
    sendStatus(remoteIp, remotePort, "OK");
    return;
  }

  float values[8];
  if (parseSetCommand(packet, values)) {
    setTargetsFromSetpoints(values);
    sendStatus(remoteIp, remotePort, "OK");
  } else {
    udp.beginPacket(remoteIp, remotePort);
    udp.print("ERR expected: SET v0 v1 v2 v3 v4 v5 v6 v7");
    udp.endPacket();
  }
}

void setupWiFi() {
  if (strlen(WIFI_SSID) > 0) {
    WiFi.mode(WIFI_STA);
    WiFi.begin(WIFI_SSID, WIFI_PASSWORD);
    Serial.print("Joining WiFi");
    while (WiFi.status() != WL_CONNECTED) {
      delay(500);
      Serial.print(".");
    }
    Serial.println();
    Serial.print("WiFi IP: ");
    Serial.println(WiFi.localIP());
  } else {
    WiFi.mode(WIFI_AP);
    WiFi.softAP(AP_SSID, AP_PASSWORD);
    Serial.print("Access point: ");
    Serial.println(AP_SSID);
    Serial.print("AP IP: ");
    Serial.println(WiFi.softAPIP());
  }
}

void setup() {
  Serial.begin(115200);
  delay(500);

  Wire.begin(I2C_SDA_PIN, I2C_SCL_PIN);
  pca.begin();
  pca.setPWMFreq(50);
  delay(10);

  for (int i = 0; i < 8; ++i) {
    currentUs[i] = servos[i].centerUs;
    targetUs[i] = servos[i].centerUs;
    lastSetpoint[i] = 0.0;
  }
  writeAllServosNow();

  setupWiFi();
  udp.begin(UDP_PORT);
  lastCommandMs = millis();
  lastServoUpdateMs = millis();

  Serial.print("UDP listening on port ");
  Serial.println(UDP_PORT);
}

void loop() {
  handleUdp();
  updateServos();
}

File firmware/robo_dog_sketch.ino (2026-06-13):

#include <Wire.h>
#include <Adafruit_PWMServoDriver.h>

Adafruit_PWMServoDriver pca = Adafruit_PWMServoDriver(0x40);

const int LED_PIN = LED_BUILTIN;
const int SERVO_CHANNEL = 0;

const int front_left_shoulder = 8; //--> min endevant, max (2750)--> enrera
const int front_left_elbow = 9; //--> min endevant, max (2750) --> enrera

const int back_left_shoulder = 10; // min: endevant, max  (2500): enderrera
const int back_left_elbow = 11; // min: endevant, max  (2750): enderrera

const int front_right_shoulder = 12; //--> min enrera, max (2500)--> endevant
const int front_right_elbow = 13; //--> min enrera, max (2750) --> endevant

const int back_right_shoulder = 14; //--> min enrera, max (2500)--> endevant
const int back_right_elbow = 15; //--> min enrera, max (2750) --> endevant


// Valors prudents inicials.
// Molts servos accepten aproximadament 1000-2000 us.
// Alguns arriben a 500-2500 us, però no comencis pels extrems.
const int SERVO_MIN_US = 500;  
const int SERVO_MAX_US = 2500; // 995 1500 --> 180º
const int SERVO_MAX2_US = 2750; //MG90s and 996 2750 --> 180º
const int SERVO_HALF_US = 1500; 
const int SERVO_HALF2_US = 1625; 


void setup() {
  pinMode(LED_PIN, OUTPUT);

  Wire.begin();

  pca.begin();
  pca.setPWMFreq(50);  // Servos típics: 50 Hz

  delay(10);
}


void fold() {
  
  pca.writeMicroseconds(back_left_elbow, SERVO_MAX2_US);
  pca.writeMicroseconds(back_right_elbow, SERVO_MIN_US);
  delay(2000);
  pca.writeMicroseconds(front_left_elbow, SERVO_MIN_US);
  pca.writeMicroseconds(front_right_elbow, SERVO_MAX2_US);
  delay(2000);
  pca.writeMicroseconds(back_left_shoulder, SERVO_MIN_US);
  pca.writeMicroseconds(back_right_shoulder, SERVO_MAX_US);
  delay(2000);
  pca.writeMicroseconds(front_left_shoulder, SERVO_MAX2_US);
  pca.writeMicroseconds(front_right_shoulder, SERVO_MIN_US);
  delay(2000);
}


void get_up() {
  pca.writeMicroseconds(front_left_shoulder, SERVO_HALF_US);
  pca.writeMicroseconds(front_right_shoulder, SERVO_HALF_US);
  delay(2000);
  pca.writeMicroseconds(back_left_shoulder, SERVO_HALF_US);
  pca.writeMicroseconds(back_right_shoulder, SERVO_HALF_US);
  delay(2000);
  pca.writeMicroseconds(front_left_elbow, SERVO_MAX2_US);
  pca.writeMicroseconds(front_right_elbow, SERVO_MIN_US);
  delay(2000);
  pca.writeMicroseconds(back_left_elbow, SERVO_MIN_US);
  pca.writeMicroseconds(back_right_elbow, SERVO_MAX2_US);
  delay(2000);
}


void loop() {
  // Posició fold
  fold();
  // pca.writeMicroseconds(back_right_elbow, SERVO_MIN_US);
  delay(5000);
  //pca.writeMicroseconds(back_right_elbow, SERVO_MAX2_US);
  //get_up();
  delay(5000);
}

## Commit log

2026-06-13 Initial commit. Basic simulation
    [MG995.stl, base2b.stl, leg1.stl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]
2026-06-18 Add MJX version. No tests!
    [crank_bot.mjx.xml, scene.mjx.xml]
2026-06-19 Change goal from velocity to reaching a point. Changed reward in a similar way.
2026-06-25 Add ESP32 robot control client
    Includes an ESP32-C3 UDP servo bridge, Python client with MuJoCo mirroring, presets, and README setup notes. Hardware path is not tested.
2026-06-26 update scene xml to avoid weight repetition and make mjx and standard xml version as close as possible
    [crank_bot.mjx.xml, scene.mjx.xml]
